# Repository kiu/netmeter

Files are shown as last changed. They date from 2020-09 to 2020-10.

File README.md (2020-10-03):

# netmeter
*netmeter* is a trio of analog panel meters showing the up-/download speed of my AVM FRITZ!Box 7360 and ping roundtrip times.

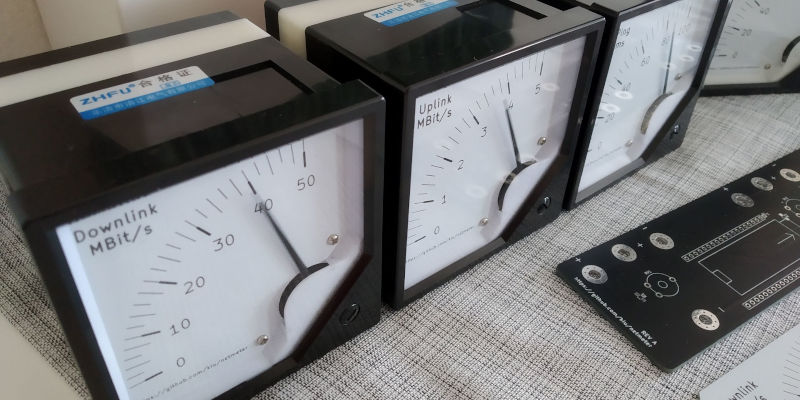
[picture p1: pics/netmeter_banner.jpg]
netmeter


Video: https://youtu.be/6VHqjQCAy3I

# Inspiration
*netmeter* is inspired by the 10 year old [megabitmeter](http://dk7sl.de/2010/11/11/megabitmeter/) and its - now defunct - commercial version [megabitmeter](http://megabitmeter.de).

# Tech Details
The [ESP32-DevKitC V4](https://www.espressif.com/en/products/devkits/esp32-devkitc) offers a powerful plug and play solution providing the core functionality of *netmeter*.
It connects to the network via wifi and polls the [UPnP](https://en.wikipedia.org/wiki/Universal_Plug_and_Play) interface of the FRITZ!Box obtaining the current transmitted and received bytes count of the WAN interface. In addition it runs a simple ping command to determine the roundtrip time. The results are transformed into PWM signals driving the meters.

The mechanical design features horizontal and vertical mounting of the panel meters. The included custom scales can be omitted to save costs. In that case a standard scale - e.g. 100A = 100 MBit/s - can be used.

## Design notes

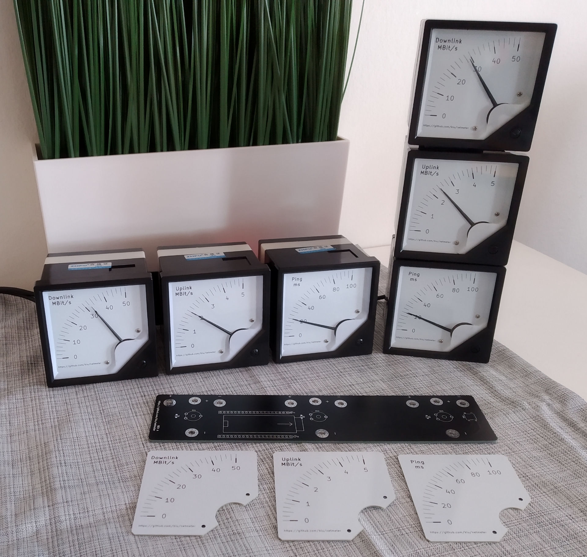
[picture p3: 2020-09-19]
pics/netmeter.jpg

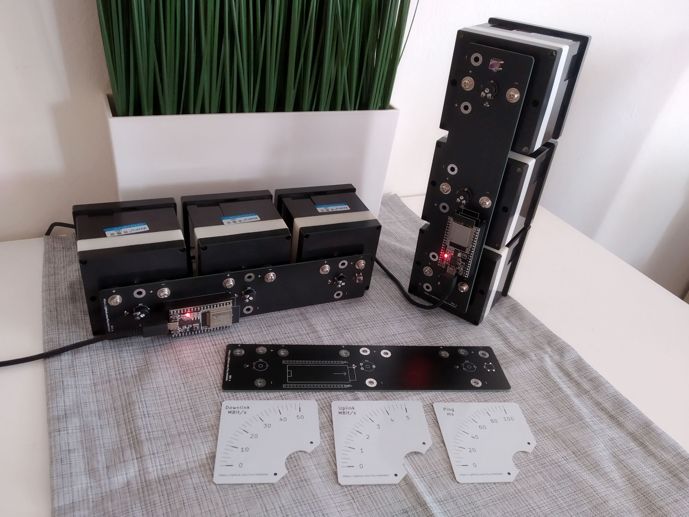
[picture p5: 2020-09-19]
pics/netmeter_back.jpg

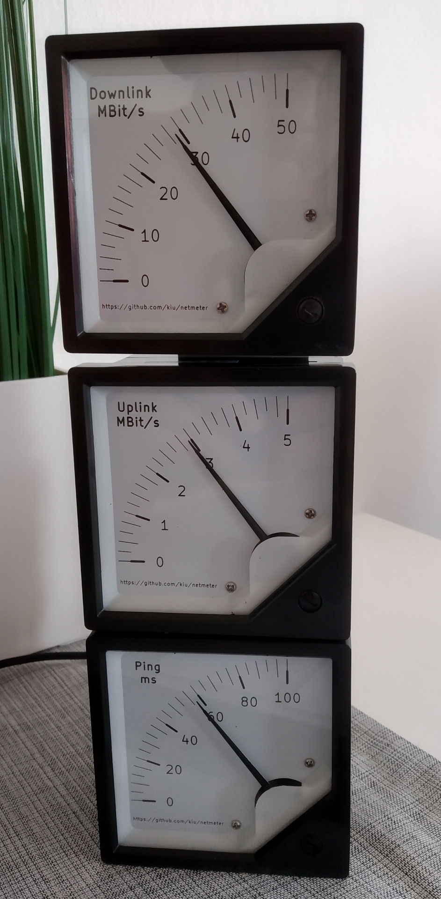
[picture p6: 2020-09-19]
pics/netmeter_vertical.jpg

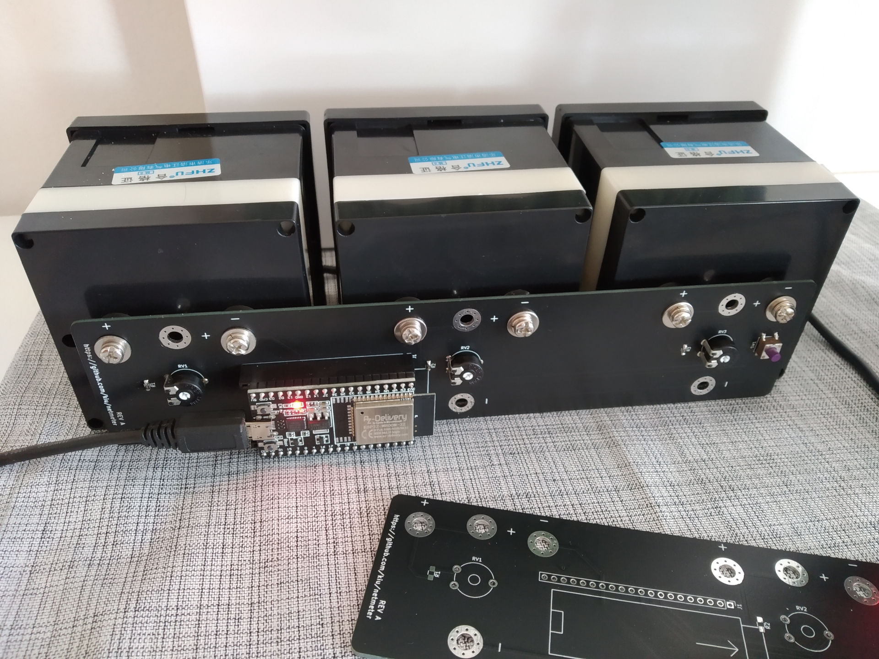
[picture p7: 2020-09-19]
pics/netmeter_horizontal_back.jpg

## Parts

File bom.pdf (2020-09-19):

BOM
Symbol | Description | Req | +VAT | Price | Price (sum) | Provider | ID
| | | | MOQ 5
- | ESP32 DevKit C V4 | 1 | 0 | 7,00 € | 7,00 € | http://www.amazon.de | B07Z83MF5W
- | Panel Meter 6C2-A (80x80 / 50A / 75mV) | 2 | 0 | 6,98 € | 13,96 € | https://de.aliexpress.com | https://de.aliexpress.com/item/32867489095.html
- | Panel Meter 6C2-A (80x80 / 100A / 75mV) | 1 | 0 | 7,72 € | 7,72 € | https://de.aliexpress.com | https://de.aliexpress.com/item/32867489095.html
J1, J2 | 1x20 2.54 | 2 | 0 | 0,38 € | 0,76 € | BL 1X20G8 2,54
R1, R2, R3 | 51R 0805 | 3 | 0 | 0,02 € | 0,06 € | http://www.reichelt.de | RND 0805 1 51
RV1, RV2, RV3 | Potentiometer PT10 220R horizontal | 3 | 0 | 0,35 € | 1,05 € | http://www.reichelt.de | PIH PT10LV1221AS
SW1 | Pushbutton SMD | 1 | 0 | 0,20 € | 0,20 € | RND 210-00203
- | | 1 | 0 | 5,52 € | 5,52 € | -

SUM
36,27 €
181,35 €

http://www.reichelt.de

http://www.reichelt.de

PCB 225x50
PCB 68x68x1
PCB 68x68x1
PCB 68x68x1

http://jlcpcb.com

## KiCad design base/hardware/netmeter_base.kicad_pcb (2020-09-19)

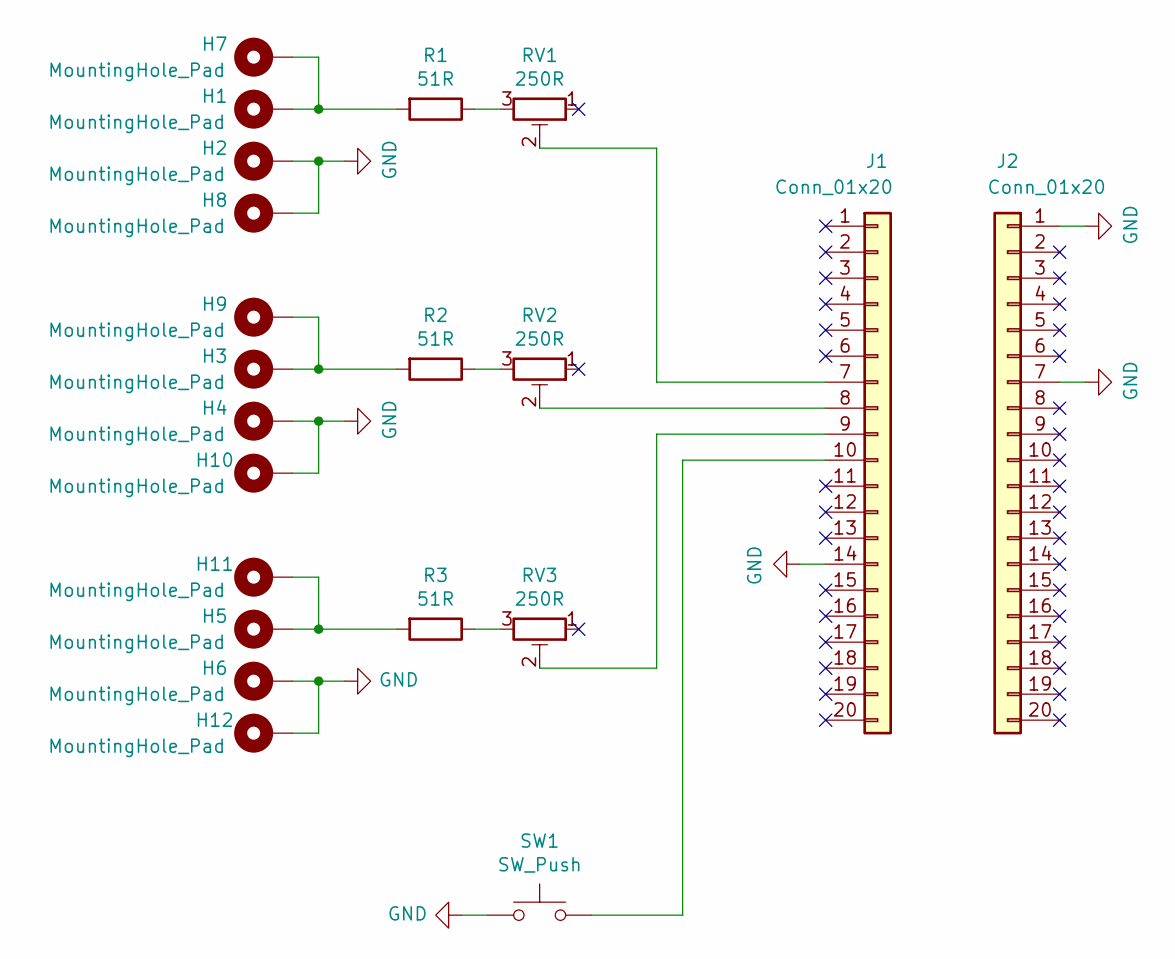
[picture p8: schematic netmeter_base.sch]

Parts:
H1, H2, H3, H4, H5, H6, H7, H8, H9, H10, H11, H12: MountingHole_Pad; MountingHole_4.3mm_M4_Pad_Via
J1, J2: Conn_01x20; Socket_Strip_Straight_1x20_Pitch2.54mm
R1, R2, R3: 51R; R_0805_HandSoldering
RV1, RV2, RV3: 250R; Potentiometer_Trimmer_Piher_PT-10v10_Horizontal_Px10.0mm_Py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
SW1: SW_Push; SW_SPST_B3S-1000

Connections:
GND: H2.1, H4.1, H6.1, H8.1, H10.1, H12.1, J1.14, J2.1, J2.7, SW1.2
unnamed: H1.1, H7.1, R1.2
unnamed: H3.1, H9.1, R2.2
unnamed: H5.1, H11.1, R3.2
unnamed: J1.7, RV1.2
unnamed: J1.8, RV2.2
unnamed: J1.9, RV3.2
unnamed: J1.10, SW1.1
unnamed: R1.1, RV1.3
unnamed: R2.1, RV2.3
unnamed: R3.1, RV3.3

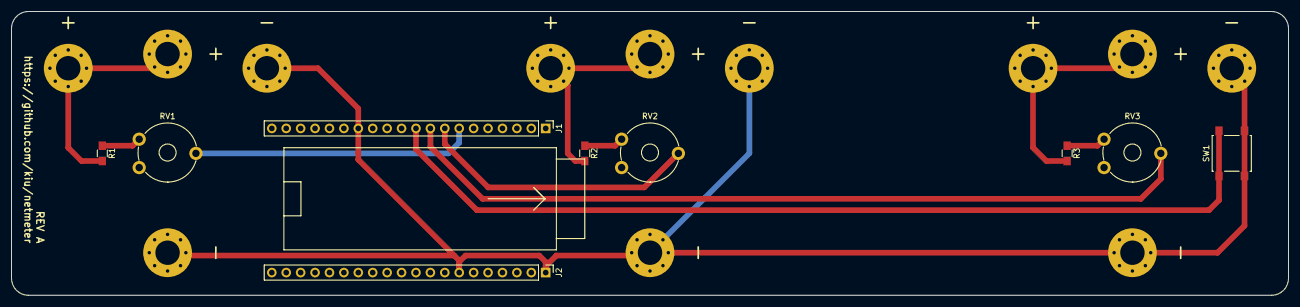
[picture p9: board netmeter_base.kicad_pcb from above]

Board: 2 copper layers, 225.0 x 50.0 mm, 21 parts (0 on the bottom side), 11 nets.

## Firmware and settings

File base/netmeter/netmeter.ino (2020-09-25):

// https://github.com/kiu/netmeter

#include <WiFi.h>
#include <HTTPClient.h>
#include <ESP32Ping.h>
#include <tinyxml2.h>
using namespace tinyxml2;

// -- -- -- --

const unsigned RX_MAX = 50000000;
const unsigned TX_MAX =  5000000;
const unsigned PING_MAX = 100;

const unsigned INTERVAL = 10;

const char* WIFI_SSID = "myssid";
const char* WIFI_PASSWORD =  "secret";
const char* URL = "http://fritz.box:49000/igdupnp/control/WANCommonIFC1";

const char* PING_HOST = "8.8.8.8";

// -- -- -- --

hw_timer_t * timer = NULL;
portMUX_TYPE timerMux = portMUX_INITIALIZER_UNLOCKED;

// -- -- -- --

const uint8_t RX_PIN = 25;
const uint8_t RX_CHANNEL = 0;
unsigned long rx_value = 0;
uint8_t rx_pwm_dst = 0;
volatile uint8_t rx_pwm_cur = 0;

const uint8_t TX_PIN = 33;
const uint8_t TX_CHANNEL = 1;
unsigned long tx_value = 0;
uint8_t tx_pwm_dst = 0;
volatile uint8_t tx_pwm_cur = 0;

const uint8_t PING_PIN = 32;
const uint8_t PING_CHANNEL = 2;
unsigned long ping_value = 0;
uint8_t ping_pwm_dst = 0;
volatile uint8_t ping_pwm_cur = 0;

const uint8_t BUTTON_PIN = 26;

// -- -- -- --

unsigned ntbr = 0;
unsigned ntbr_last = 0;

unsigned ntbs = 0;
unsigned ntbs_last = 0;

unsigned long req_millis_last = 0;

// -- -- -- --

boolean mode_test = false;
uint8_t mode_value = 0x00;
volatile boolean mode_switch = false;
volatile unsigned long mode_micros = micros();

// -- -- -- --

void wifi_connect() {
  if (WiFi.status() == WL_CONNECTED) {
    return;
  }

  while (WiFi.status() != WL_CONNECTED) {
    WiFi.disconnect();
    Serial.printf("WiFi scan: %d\n", WiFi.scanNetworks());
    Serial.printf("WiFi connecting: %s\n", WIFI_SSID);
    WiFi.begin(WIFI_SSID, WIFI_PASSWORD);
    while (WiFi.status() == WL_IDLE_STATUS || WiFi.status() == WL_DISCONNECTED) {
      delay(100);
    }
  }

  Serial.print("WiFi connected: ");
  Serial.println(WiFi.localIP());
}

void run_query() {
  HTTPClient http;

  http.begin(URL);
  http.addHeader("Content-Type", "text/xml");
  http.addHeader("User-Agent", "esp-idf/1.0 esp32");
  http.addHeader("Charset", "utf-8");
  http.addHeader("SoapAction", "urn:schemas-upnp-org:service:WANCommonInterfaceConfig:1#GetAddonInfos");

  Serial.printf("HTTP: %s\n", URL);
  int rc = http.POST("<?xml version=\"1.0\" encoding=\"utf-8\" ?><s:Envelope s:encodingStyle=\"http://schemas.xmlsoap.org/soap/encoding/\" xmlns:s=\"http://schemas.xmlsoap.org/soap/envelope/\"><s:Body><u:GetCommonLinkProperties xmlns:u=\"urn:schemas-upnp-org:service:WANCommonInterfaceConfig:1\" /></s:Body></s:Envelope>");

  Serial.printf("HTTP: %d\n", rc);
  if (rc != 200) {
    http.end();
    return;
  }

  unsigned long tmp_millis = millis();

  String res = http.getString();  //Get the response to the request

  http.end();

  /*
    <?xml version="1.0" encoding="utf-8"?>
    <s:Envelope xmlns:s="http://schemas.xmlsoap.org/soap/envelope/" s:encodingStyle="http://schemas.xmlsoap.org/soap/encoding/">
    <s:Body>
    <u:GetAddonInfosResponse xmlns:u="urn:schemas-upnp-org:service:WANCommonInterfaceConfig:1">
    <NewByteSendRate>1926</NewByteSendRate>
    <NewByteReceiveRate>3147</NewByteReceiveRate>
    <NewPacketSendRate>24</NewPacketSendRate>
    <NewPacketReceiveRate>13</NewPacketReceiveRate>
    <NewTotalBytesSent>4113851316</NewTotalBytesSent>
    <NewTotalBytesReceived>1149211977</NewTotalBytesReceived>
    <NewAutoDisconnectTime>0</NewAutoDisconnectTime>
    <NewIdleDisconnectTime>0</NewIdleDisconnectTime>
    <NewDNSServer1>212.18.3.5</NewDNSServer1>
    <NewDNSServer2>212.18.3.5</NewDNSServer2>
    <NewVoipDNSServer1>0.0.0.0</NewVoipDNSServer1>
    <NewVoipDNSServer2>0.0.0.0</NewVoipDNSServer2>
    <NewUpnpControlEnabled>0</NewUpnpControlEnabled>
    <NewRoutedBridgedModeBoth>0</NewRoutedBridgedModeBoth>
    </u:GetAddonInfosResponse>
    </s:Body>
    </s:Envelope>
  */

  XMLDocument xmlDocument;
  if (xmlDocument.Parse(res.c_str()) != XML_SUCCESS) {
    Serial.println("Could not parse XML");
    Serial.println(res);
    return;
  }

  XMLNode * root = xmlDocument.FirstChild();
  if (root == nullptr) {
    Serial.println("XML has no root");
    Serial.println(res);
    return;
  }

  XMLElement * e_envelop = root->NextSiblingElement(); // <s:Envelope>
  if (e_envelop == nullptr) {
    Serial.println("XML has no <s:Envelope>");
    Serial.println(res);
    return;
  }

  XMLElement * e_body = e_envelop->FirstChildElement(); // <s:Body>
  if (e_body == nullptr) {
    Serial.println("XML has no <s:Body>");
    Serial.println(res);
    return;
  }

  XMLElement * e_addon = e_body->FirstChildElement(); // <u:GetAddonInfosResponse>
  if (e_addon == nullptr) {
    Serial.println("XML has no <u:GetAddonInfosResponse>");
    Serial.println(res);
    return;
  }

  XMLElement * el_ntbr = e_addon->FirstChildElement("NewTotalBytesReceived");
  if (el_ntbr == nullptr) {
    Serial.println("XML has no <NewTotalBytesReceived>");
    Serial.println(res);
    return;
  }
  el_ntbr->QueryUnsignedText(&ntbr);

  XMLElement * el_ntbs = e_addon->FirstChildElement("NewTotalBytesSent");
  if (el_ntbs == nullptr) {
    Serial.println("XML has no <NewTotalBytesSent>");
    Serial.println(res);
    return;
  }
  el_ntbs->QueryUnsignedText(&ntbs);

  unsigned diff = (tmp_millis - req_millis_last) / 1000;

  if (ntbr_last != 0) {
    unsigned rx_tmp = (ntbr - ntbr_last) * 8 / diff;
    if (rx_tmp > RX_MAX) {
      rx_tmp = RX_MAX;
    }
    rx_value = rx_tmp;
  }

  if (ntbs_last != 0) {
    unsigned tx_tmp = (ntbs - ntbs_last) * 8 / diff;
    if (tx_tmp > TX_MAX) {
      tx_tmp = TX_MAX;
    }
    tx_value = tx_tmp;
  }

  ntbr_last = ntbr;
  ntbs_last = ntbs;
  req_millis_last = tmp_millis;

  Serial.printf("RX: %d bit/s\n", rx_value);
  Serial.printf("TX: %d bit/s\n", tx_value);
  rx_pwm_dst = (uint8_t)((float) rx_value / (float) RX_MAX * 255.0);
  tx_pwm_dst = (uint8_t)((float) tx_value / (float) TX_MAX * 255.0);
}

void run_ping() {
  bool ret = Ping.ping(PING_HOST, 1);
  if (!ret) {
    Serial.println("Ping failed");
    return;
  }

  unsigned ping_tmp = (unsigned)Ping.averageTime();
  if (ping_tmp > PING_MAX) {
    ping_tmp = PING_MAX;
  }
  ping_value = ping_tmp;

  Serial.printf("Ping: %d ms\n", ping_value);
  ping_pwm_dst = (uint8_t)((float) ping_value / (float) PING_MAX * 255.0);
}

void set_all(uint8_t value) {
  Serial.printf("Set value: %d\n", value);
  rx_pwm_dst = value;
  tx_pwm_dst = value;
  ping_pwm_dst = value;
}

void run_test() {
  if (mode_value == 0x00) {
    mode_value = 0xFF;
  } else {
    mode_value -= 0x33;
  }
  set_all(mode_value);
}

uint8_t IRAM_ATTR tick_step(uint8_t chan, uint8_t current, uint8_t target) {
  if (current == target) {
    return current;
  }
  if (current > target) {
    current--;
    ledcWrite(chan, current);
  }
  if (current < target) {
    current++;
    ledcWrite(chan, current);
  }
  return current;
}

void IRAM_ATTR tick() {
  portENTER_CRITICAL_ISR(&timerMux);
  rx_pwm_cur = tick_step(RX_CHANNEL, rx_pwm_cur, rx_pwm_dst);
  tx_pwm_cur = tick_step(TX_CHANNEL, tx_pwm_cur, tx_pwm_dst);
  ping_pwm_cur = tick_step(PING_CHANNEL, ping_pwm_cur, ping_pwm_dst);
  portEXIT_CRITICAL_ISR(&timerMux);
}

void IRAM_ATTR handleInterrupt() {
  if ((long)(micros() - mode_micros) >= 500 * 1000) {
    mode_switch = true;
    mode_micros = micros();
  }
}

void setup() {
  Serial.begin(115200);
  delay(1000);
  Serial.println("https://github.com/kiu/netmeter v0.2");

  pinMode(RX_PIN, OUTPUT);
  ledcSetup(RX_CHANNEL, 500, 8);
  ledcAttachPin(RX_PIN, RX_CHANNEL);

  pinMode(TX_PIN, OUTPUT);
  ledcSetup(TX_CHANNEL, 500, 8);
  ledcAttachPin(TX_PIN, TX_CHANNEL);

  pinMode(PING_PIN, OUTPUT);
  ledcSetup(PING_CHANNEL, 500, 8);
  ledcAttachPin(PING_PIN, PING_CHANNEL);

  pinMode(BUTTON_PIN, INPUT_PULLUP);
  attachInterrupt(digitalPinToInterrupt(BUTTON_PIN), handleInterrupt, FALLING);

  timer = timerBegin(0, 80, true);
  timerAttachInterrupt(timer, &tick, true);
  timerAlarmWrite(timer, 10000, true);
  timerAlarmEnable(timer);

  set_all(0xFF);
  delay(4000);
  set_all(0x00);
  delay(4000);

  Serial.print("WiFi MAC: ");
  Serial.println(WiFi.macAddress());
}

void loop() {
  if (mode_test) {
    run_test();
  } else {
    wifi_connect();
    Serial.println("-- -- --");
    run_query();
    run_ping();
  }

  for (uint16_t i = 0; i < 10 * INTERVAL; i++) {
    if (mode_switch) {
      mode_switch = false;
      mode_test = !mode_test;
      mode_value = 0x00;
      Serial.printf("Switched mode to: %s\n", mode_test ? "true" : "false");
      return;
    }
    delay(100);
  }
}

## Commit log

2020-09-19 Initial REV A
    [bom.ods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]
2020-09-25 Fixed kernel crashes Switching between modes is quick now ...
    [netmeter.ino]
